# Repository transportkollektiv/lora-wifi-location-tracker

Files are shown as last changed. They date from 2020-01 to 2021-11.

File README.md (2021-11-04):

# LoRa Wifi Location Tracker

This is a ESP8266 and RFM96 based for low power geolocation tracker. It uses wifi networks for location discovery instead of GPS. Accuracy is not as good as GPS and locations can only be calculated if there is any nearby wifi networks. For location calculation a wifi geolocate service like [mozilla](https://location.services.mozilla.com/) or [google](https://developers.google.com/maps/documentation/geolocation/intro) is needed.
The location is not calculated on the device. The small data for calculating the location is send out via LoRaWAN and can then calculated on server. You can use [cycle-ttn-wifi](https://github.com/transportkollektiv/cykel-ttn-wifi) as location calculation bridge.

## Hardware

You can find .brd and .sch files (created in eagle) and the ready to use gerber files for the *lortinchen*-PCB in the `hardware` folder. More info in [`README.md`](./hardware/README.md) in the hardware folder.
The board can be power by two AA batteries.

## Firmware configuration

For LoRaWAN configuration rename `config.sample.h` to `config.h` and fill the file with your LoRaWAN device config. Development, configuration, building and flashing can all be done in [PlatformIO](https://platformio.org/).
To make the wifi scan more effective, we currently have to patch `ESP8266WiFiScan`. Call `make patch` to modify the file in your platformio framework-arduinoespressif8266 - or look into the `ESP8266WiFiScan.patch` if you want to make the changes yourself.
More on physically flashing firmware at `hardware/README.md`.

## TTN decoder script

The [TTN](https://www.thethingsnetwork.org/) payload decoder script can be found in [`ttn-decoder-script.js`](./ttn-decoder-script.js) for TTN Stack V2 or in [`ttnv3-decoder-script.js`](./ttnv3-decoder-script.js) if you are using TTN Stack V3.

## Improve coverage

You can improve [coverage of mozillas location service](https://location.services.mozilla.com/map) using the [mozilla stumbler app](https://play.google.com/store/apps/details?id=org.mozilla.mozstumbler) for android or by [activating location data collection in firefox for android](https://support.mozilla.org/en-US/kb/improve-mozilla-location-services-turning-location).

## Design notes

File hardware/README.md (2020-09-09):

# Lortinchen

Lortinchen is a small PCB combining an ESP8266 with an RFM96 for Lora Communication. We use this as a Wifi location tracker in our OpenBike project to track our Bikes.

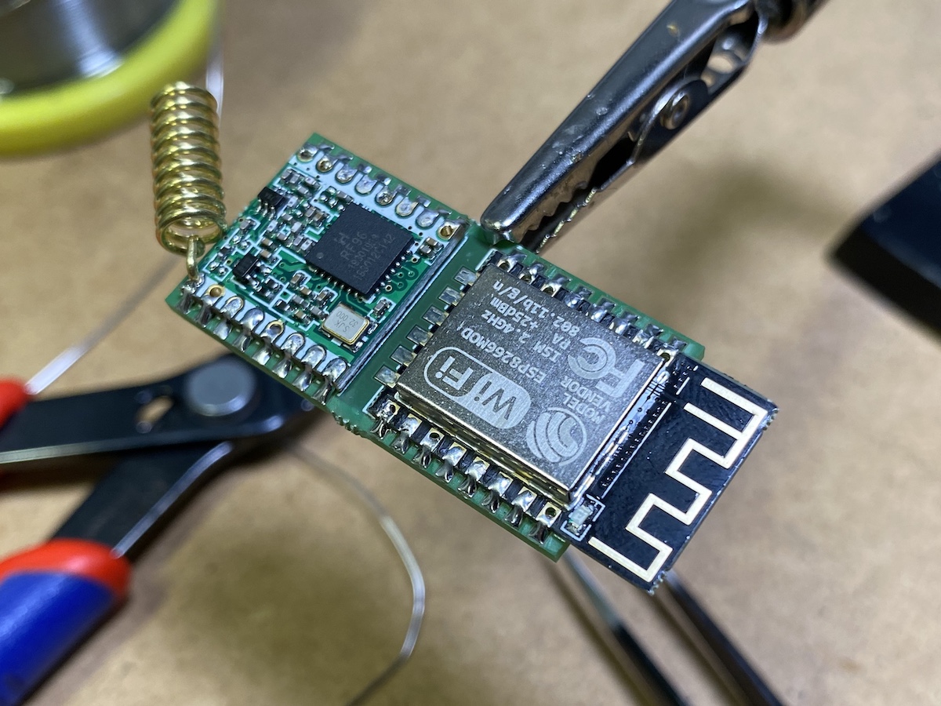
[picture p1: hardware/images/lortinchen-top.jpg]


## Flash firmware

To flash firmware before soldering the ESP on the PCB, you can use an *ESP-12 test board fixture programmer*. So you don't need to solder a connection to a Serial-USB-Adapter and don't need the flash and reset buttons.

If you want to update or flash firmware after soldering, you need the 1K resistors and the flash and reset  buttons. Then solder GND, RX, TX and 3V to your Serial-USB-Connector. To go into flash-mode hold flash button, press reset, then release flash button. Now you can flash the firmware from PlatformIO.

## Parts

### Required

 * ESP8266 Modules (ESP-12E or ESP-12F with on board PCB antenna or ESP-07 or ESP-07S for external antennas)
 * RFM96
 * 5x 10K 0603 resistors
 * 1x 100uF (107C/6032) capacitor

### Optional

 * 2x 1K 0603 resistors (for serial connection and flashing after soldering)
 * 2x SMD 2Pin 3X4 mm tactile buttons (for easy flashing and resetting after soldering)
 * 1x AMS111733 LDO (only if power supply is more than 3,3V, but will consume more power.)
 * 1x 680K and 1x 100K 0603 resistor (for voltage devider), now supported in the firmware to mesure voltage. If you don't use the AMS111733, connect the 12V and the 3V Pin to mesure voltage.

## Power supply

The Board can be powered by two AA (LR6) batteries on the 3V3 pad, without the AMS111733 installed. Our first test-devices are running now for around 4 months without changing batteries.

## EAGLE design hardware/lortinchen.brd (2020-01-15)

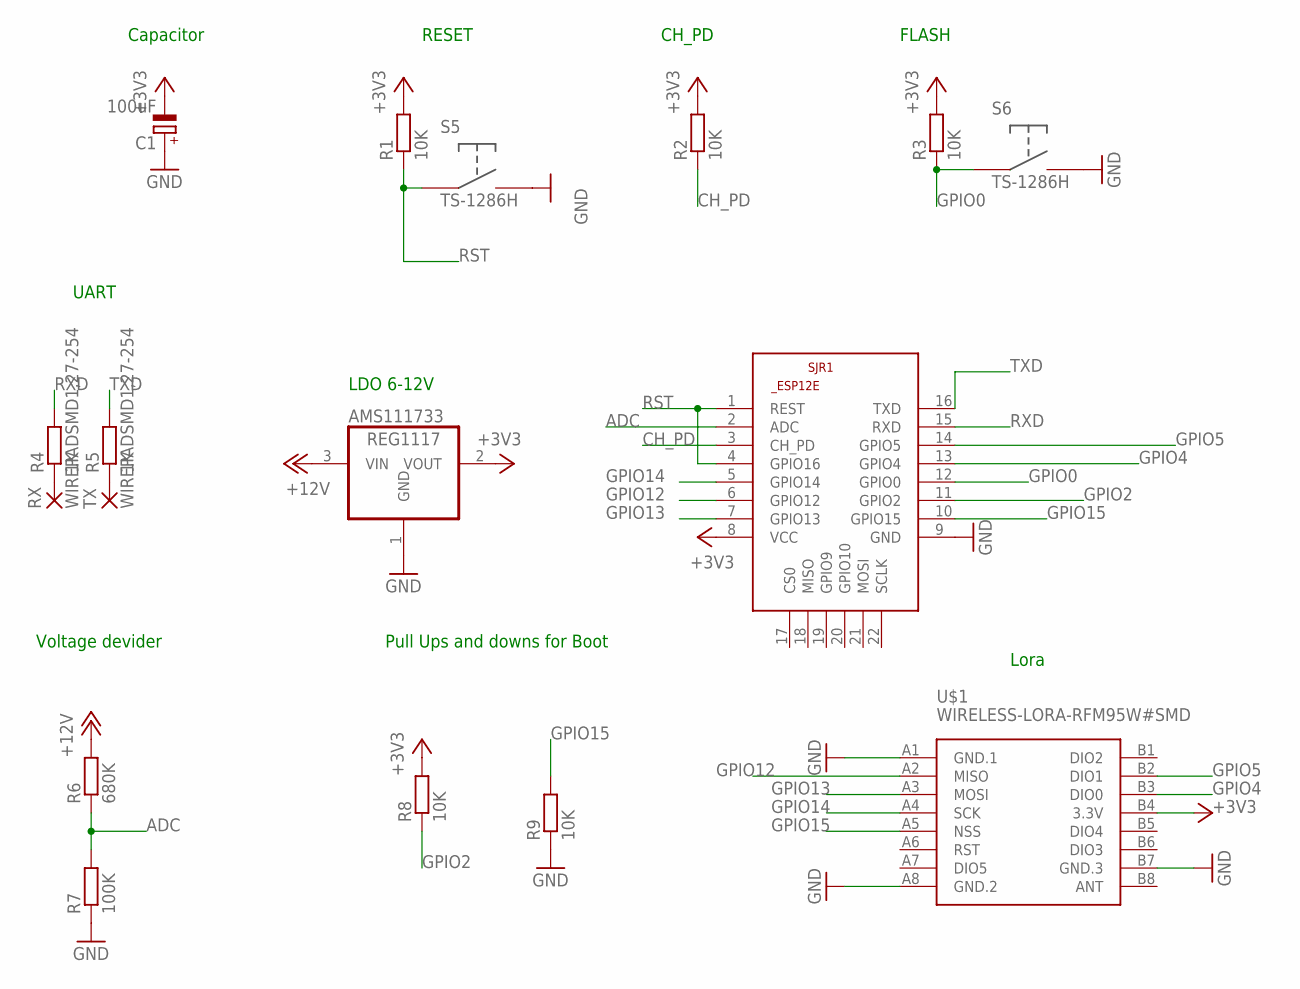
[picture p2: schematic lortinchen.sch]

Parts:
AMS111733: REG1117; SOT223
C1: 100uF; C/6032-28R
R1, R2, R3, R8, R9: 10K; R0603
R4, R5: 1K; R0603
R6: 680K; R0603
R7: 100K; R0603
RX: WIREPADSMD1,27-254; SMD1,27-2,54
S5, S6: TS-1286H; TS-1268H
SJR1: ESP8266-12EESP12E; ESP8266-ESP12E
TX: WIREPADSMD1,27-254; SMD1,27-2,54
U$1: WIRELESS-LORA-RFM95W#SMD

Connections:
+3V3: AMS111733.2 (VOUT), C1.-, R1.2, R2.2, R3.2, R8.2, SJR1.8 (VCC), U$1.B4 (3.3V)
+12V: AMS111733.3 (VIN), R6.2
ADC: R6.1, R7.2, SJR1.2 (ADC)
CH_PD: R2.1, SJR1.3 (CH_PD)
GND: AMS111733.1 (GND), C1.+, R7.1, R9.1, S5.P$2, S6.P$2, SJR1.9 (GND), U$1.A1 (GND.1), U$1.A8 (GND.2), U$1.B7 (GND.3)
GPIO0: R3.1, S6.P$1, SJR1.12 (GPIO0)
GPIO2: R8.1, SJR1.11 (GPIO2)
GPIO4: SJR1.13 (GPIO4), U$1.B3 (DIO0)
GPIO5: SJR1.14 (GPIO5), U$1.B2 (DIO1)
GPIO12: SJR1.6 (GPIO12), U$1.A2 (MISO)
GPIO13: SJR1.7 (GPIO13), U$1.A3 (MOSI)
GPIO14: SJR1.5 (GPIO14), U$1.A4 (SCK)
GPIO15: R9.2, SJR1.10 (GPIO15), U$1.A5 (NSS)
unnamed: R4.1, RX.1
unnamed: R5.1, TX.1
RST: R1.1, S5.P$1, SJR1.1 (REST), SJR1.4 (GPIO16)
RXD: R4.2, SJR1.15 (RXD)
TXD: R5.2, SJR1.16 (TXD)

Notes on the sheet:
RESET
CH_PD
FLASH
LDO 6-12V
Capacitor
UART
Voltage devider
Pull Ups and downs for Boot
Lora

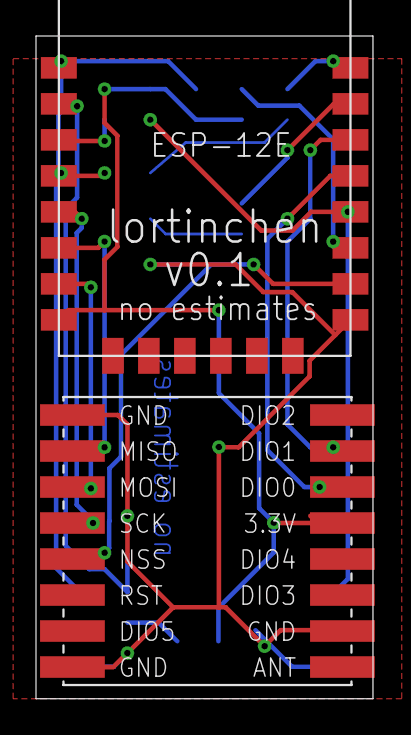
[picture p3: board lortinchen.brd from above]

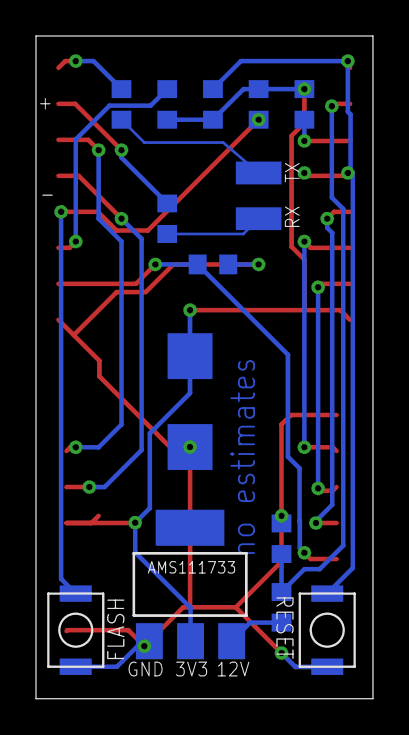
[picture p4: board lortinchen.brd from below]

Board: 2 copper layers, 18.7 x 36.8 mm, 17 parts (15 on the bottom side), 18 nets.

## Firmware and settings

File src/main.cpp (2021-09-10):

// we use our own config.h
#define ARDUINO_LMIC_PROJECT_CONFIG_H_SUPPRESS 1
#include "config.h"

#include <lmic.h>
#include <hal/hal.h>
#include <SPI.h>
#include <ESP8266WiFi.h>

void os_getArtEui (u1_t* buf) { memcpy_P(buf, APPEUI, 8); }
void os_getDevEui (u1_t* buf) { memcpy_P(buf, DEVEUI, 8); }
void os_getDevKey (u1_t* buf) { memcpy_P(buf, APPKEY, 16); }

u1_t NWKSKEY[16] = {};
u1_t APPSKEY[16] = {};
u4_t DEVADDR = 0;

static osjob_t sendjob;

const uint8 PAYLOAD_VERSION = 2;

// Pin mapping
const lmic_pinmap lmic_pins = {
    .nss = D8,
    .rxtx = LMIC_UNUSED_PIN,
    .rst = LMIC_UNUSED_PIN,
    .dio = { D1, D2, LMIC_UNUSED_PIN },
};

#define DATAVALID 0xACF2AFC2                     // Pattern for data valid in EEPROM/RTC memory
                                                 // Change if you want OTAA to renew keys.

struct savdata_t                                 // Structure of data to be saved over reset
{
  uint32_t dataValid;                            // DATAVALID if valid data (joined)
  uint8_t  devaddr[4];                           // Device address after join
  uint8_t  nwkKey[16];                           // Network session key after join
  uint8_t  artKey[16];                           // Aplication session key after join
  uint32_t seqnoUp;                              // Sequence number                      
};
savdata_t savdata;

void do_send(osjob_t* );
void saveLoraToRTCMemory();
void loadLoraFromRTCMemory();

void onEvent (ev_t ev) {
    Serial.print(os_getTime());
    Serial.print(": ");
    switch(ev) {
        case EV_SCAN_TIMEOUT:
            Serial.println(F("EV_SCAN_TIMEOUT"));
            break;
        case EV_BEACON_FOUND:
            Serial.println(F("EV_BEACON_FOUND"));
            break;
        case EV_BEACON_MISSED:
            Serial.println(F("EV_BEACON_MISSED"));
            break;
        case EV_BEACON_TRACKED:
            Serial.println(F("EV_BEACON_TRACKED"));
            break;
        case EV_JOINING:
            Serial.println(F("EV_JOINING"));
            break;
        case EV_JOINED:
            Serial.println(F("EV_JOINED"));
            {
                u4_t netid = 0;
                devaddr_t devaddr = 0;
                u1_t nwkKey[16];
                u1_t artKey[16];
                LMIC_getSessionKeys(&netid, &devaddr, nwkKey, artKey);
            }
            LMIC_setLinkCheckMode(0);
            break;
        case EV_RFU1:
            Serial.println(F("EV_RFU1"));
            break;
        case EV_JOIN_FAILED:
            Serial.println(F("EV_JOIN_FAILED"));
            break;
        case EV_REJOIN_FAILED:
            Serial.println(F("EV_REJOIN_FAILED"));
            break;
        case EV_TXCOMPLETE:
            Serial.println(F("EV_TXCOMPLETE (includes waiting for RX windows)"));
            if (LMIC.txrxFlags & TXRX_ACK)
              Serial.println(F("Received ack"));
            if (LMIC.dataLen) {
              Serial.println(F("Received "));
              Serial.println(LMIC.dataLen);
              Serial.println(F(" bytes of payload"));
            }
            // Schedule next transmission
            //os_setTimedCallback(&sendjob, os_getTime()+sec2osticks(TX_INTERVAL), do_send);
            
            //LMIC_shutdown();
            saveLoraToRTCMemory();
            
            //Einschlafen
            ESP.deepSleep(SLEEP_DURATION);
            break;
        case EV_LOST_TSYNC:
            Serial.println(F("EV_LOST_TSYNC"));
            break;
        case EV_RESET:
            Serial.println(F("EV_RESET"));
            break;
        case EV_RXCOMPLETE:
            // data received in ping slot
            Serial.println(F("EV_RXCOMPLETE"));
            break;
        case EV_LINK_DEAD:
            Serial.println(F("EV_LINK_DEAD"));
            break;
        case EV_LINK_ALIVE:
            Serial.println(F("EV_LINK_ALIVE"));
            break;
         default:
            Serial.println(F("Unknown event"));
            break;
    }
}
int scanWifi(byte* data);
uint8 getVoltage();
void do_send(osjob_t* j){
    // Check if there is not a current TX/RX job running
    if (LMIC.opmode & OP_TXRXPEND) {
        Serial.println(F("OP_TXRXPEND, not sending"));
    } else {
        // Prepare upstream data transmission at the next possible time.
        
        byte data[53];
        int len = scanWifi(data+2)+2;
        data[0] = PAYLOAD_VERSION;
        data[1] = getVoltage();
        LMIC_setTxData2(1, data, len, 0);
        Serial.println(F("Packet queued"));
    }
    // Next TX is scheduled after TX_COMPLETE event.
}

uint8 getVoltage() {
    int voltageRawValue = analogRead(A0);
    /*Serial.printf("voltageRawValue: %i\n", voltageRawValue);
    Serial.printf("A0 voltage: %f\n", ((double)voltageRawValue)/(double)1024);
    double correctedVoltage = ((double)voltageRawValue)/(double)1024*7.8;
    Serial.printf("corrected voltage: %f\n", correctedVoltage);*/
    uint8 oneByteValue = voltageRawValue/4;
    //Serial.printf("oneByteValue: %f\n", oneByteValue);
    return oneByteValue;
}

struct minWifi {
  int id;
  int rssi;
};

int wifiComparer(const void * w1, const void * w2) {
  const struct minWifi *elem1 = (minWifi*)w1;    
  const struct minWifi *elem2 = (minWifi*)w2;
  return ( elem2->rssi - elem1->rssi );
}

int scanWifi(byte* data) {
  WiFi.mode(WIFI_STA);
  int n = WiFi.scanNetworks(false, false);
  //we dont need the wifi anymore
  WiFi.forceSleepBegin();
  String ssid;
  uint8_t encryptionType;
  int32_t RSSI;
  uint8_t* BSSID;
  int32_t channel;
  bool isHidden;


  minWifi wifilist[n];
  for (int i = 0; i < n; i++) {
    WiFi.getNetworkInfo(i, ssid, encryptionType, RSSI, BSSID, channel, isHidden);
    wifilist[i] = {i, RSSI};
  }
  qsort(wifilist, n, sizeof(minWifi), wifiComparer);

  int datalen = 0;
  for (int i = 0; i < n; i++)
  {
    WiFi.getNetworkInfo(wifilist[i].id, ssid, encryptionType, RSSI, BSSID, channel, isHidden);
    Serial.print("WIFI: ");
    Serial.println(ssid);
    memcpy(data+i*6, BSSID, 6);
    datalen = i*6+6;
    if (i==7) {
      break;
    }
  }

  return datalen;
}

void setup() {
    Serial.begin(115200);
    Serial.println(F("Starting"));
    Serial.printf("DEVADDR: 0x%8X\n", DEVADDR);

    #ifdef VCC_ENABLE
    // For Pinoccio Scout boards
    pinMode(VCC_ENABLE, OUTPUT);
    digitalWrite(VCC_ENABLE, HIGH);
    delay(1000);
    #endif

    // LMIC init
    os_init();
    // Reset the MAC state. Session and pending data transfers will be discarded.
    LMIC_reset();

    // Set static session parameters. Instead of dynamically establishing a session
    // by joining the network, precomputed session parameters are be provided.
    #ifdef PROGMEM
    // On AVR, these values are stored in flash and only copied to RAM
    // once. Copy them to a temporary buffer here, LMIC_setSession will
    // copy them into a buffer of its own again.
    //uint8_t appskey[sizeof(APPSKEY)];
    //uint8_t nwkskey[sizeof(NWKSKEY)];
    //memcpy_P(appskey, APPSKEY, sizeof(APPSKEY));
    //memcpy_P(nwkskey, NWKSKEY, sizeof(NWKSKEY));
    //LMIC_setSession (0x13, DEVADDR, nwkskey, appskey);
    #else
    // If not running an AVR with PROGMEM, just use the arrays directly
    //LMIC_setSession (0x13, DEVADDR, NWKSKEY, APPSKEY);
    #endif
    loadLoraFromRTCMemory();

    #if defined(CFG_eu868)
    // Set up the channels used by the Things Network, which corresponds
    // to the defaults of most gateways. Without this, only three base
    // channels from the LoRaWAN specification are used, which certainly
    // works, so it is good for debugging, but can overload those
    // frequencies, so be sure to configure the full frequency range of
    // your network here (unless your network autoconfigures them).
    // Setting up channels should happen after LMIC_setSession, as that
    // configures the minimal channel set.
    // NA-US channels 0-71 are configured automatically
    LMIC_setupChannel(0, 868100000, DR_RANGE_MAP(DR_SF12, DR_SF7),  BAND_CENTI);      // g-band
    LMIC_setupChannel(1, 868300000, DR_RANGE_MAP(DR_SF12, DR_SF7B), BAND_CENTI);      // g-band
    LMIC_setupChannel(2, 868500000, DR_RANGE_MAP(DR_SF12, DR_SF7),  BAND_CENTI);      // g-band
    LMIC_setupChannel(3, 867100000, DR_RANGE_MAP(DR_SF12, DR_SF7),  BAND_CENTI);      // g-band
    LMIC_setupChannel(4, 867300000, DR_RANGE_MAP(DR_SF12, DR_SF7),  BAND_CENTI);      // g-band
    LMIC_setupChannel(5, 867500000, DR_RANGE_MAP(DR_SF12, DR_SF7),  BAND_CENTI);      // g-band
    LMIC_setupChannel(6, 867700000, DR_RANGE_MAP(DR_SF12, DR_SF7),  BAND_CENTI);      // g-band
    LMIC_setupChannel(7, 867900000, DR_RANGE_MAP(DR_SF12, DR_SF7),  BAND_CENTI);      // g-band
    LMIC_setupChannel(8, 868800000, DR_RANGE_MAP(DR_FSK,  DR_FSK),  BAND_MILLI);      // g2-band
    // TTN defines an additional channel at 869.525Mhz using SF9 for class B
    // devices' ping slots. LMIC does not have an easy way to define set this
    // frequency and support for class B is spotty and untested, so this
    // frequency is not configured here.
    #elif defined(CFG_us915)
    // NA-US channels 0-71 are configured automatically
    // but only one group of 8 should (a subband) should be active
    // TTN recommends the second sub band, 1 in a zero based count.
    // https://github.com/TheThingsNetwork/gateway-conf/blob/master/US-global_conf.json
    LMIC_selectSubBand(1);
    #endif

    // Disable link check validation
    LMIC_setLinkCheckMode(0);

    // TTN uses SF9 for its RX2 window.
    LMIC.dn2Dr = DR_SF9;

    // Set data rate and transmit power for uplink (note: txpow seems to be ignored by the library)
    LMIC_setDrTxpow(DR_SF7,14);

    // Start job
    do_send(&sendjob);
}

void saveLoraToRTCMemory() {
    memcpy(savdata.devaddr, &LMIC.devaddr, 4);
    memcpy(savdata.nwkKey, LMIC.nwkKey, 16);
    memcpy(savdata.artKey, LMIC.artKey, 16);
    savdata.seqnoUp = LMIC.seqnoUp;
    savdata.dataValid = DATAVALID;
    ESP.rtcUserMemoryWrite(0, (uint32_t*) &savdata, sizeof(savdata));
}

void loadLoraFromRTCMemory() {
    ESP.rtcUserMemoryRead(0, (uint32_t*) &savdata, sizeof(savdata));
    if (savdata.dataValid == DATAVALID) {
        memcpy((uint8_t*)&DEVADDR, savdata.devaddr, sizeof(DEVADDR));
        memcpy(NWKSKEY, savdata.nwkKey, sizeof(NWKSKEY));          // LoRaWAN NwkSKey, network session key.
        memcpy(APPSKEY, savdata.artKey, sizeof(APPSKEY));
        LMIC_setSession(0x1, DEVADDR, NWKSKEY, APPSKEY);
        LMIC.seqnoUp = savdata.seqnoUp;
    }
}

void loop() {
    os_runloop_once();
}

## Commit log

2020-01-15 added config sample
2020-01-15 added hardware
    [lortinchen.brd, lortinchen.sch]
2020-01-15 added notes to power supply and power consumption
2020-07-23 decoder script with payload versions and voltage
2020-07-23 Payload version and Battery voltage
2020-07-28 decoder script: fixed null voltage values, toFixed
2020-08-12 Update README.md
    added footprint for 100uF capacitor
2021-02-26 switched to MCCI LMIC Lorawan libary

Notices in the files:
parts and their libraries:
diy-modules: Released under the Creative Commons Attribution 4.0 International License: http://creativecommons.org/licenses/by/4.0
